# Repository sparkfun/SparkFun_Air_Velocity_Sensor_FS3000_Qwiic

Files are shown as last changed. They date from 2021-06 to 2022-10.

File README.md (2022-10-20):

SparkFun Air Velocity Sensor Breakout - FS3000 (Qwiic)
========================================

<table class="table table-hover table-striped table-bordered">
  <tr align="center">
   <td><a href="https://www.sparkfun.com/products/18377">SparkFun Air Velocity Sensor Breakout - FS3000-1005 (Qwiic)</a></td>
   <td><a href="https://www.sparkfun.com/products/18768">SparkFun Air Velocity Sensor Breakout - FS3000-1015 (Qwiic)</a></td>
  </tr>
  <tr align="center">
   <td><i>SparkFun Air Velocity Sensor Breakout <br /> FS3000-1005 (Qwiic) <br /> [ <a href="https://www.sparkfun.com/products/18377">SEN-18377</a> ]</i></td>
   <td><i>SparkFun Air Velocity Sensor Breakout <br /> FS3000-1015 (Qwiic) <br /> [ <a href="https://www.sparkfun.com/products/18768">SEN-18768</a> ]</i></td>
  </tr>
</table>

The SparkFun Air Velocity Sensor Breakout - FS3000 (Qwiic) makes it easy to use the Renesas FS3000 module. The FS3000 is a surface-mount type air velocity module utilizing a MEMS thermopile-based sensor. The FS3000 features a digital output with 12-bit resolution. The sensor comprises a "solid" thermal isolation technology and siliconcarbide coating to protect it from abrasive wear and water condensation. The FS3000 features a compact design fit for low profile enclosures.

There are two versions of this sensor with different upper ranges (1005/1015). This SparkFun product breaks out both versions on separate breakout boards: the 1005 version which can sense 0-7.23m/s (0-16.17mph) and 1015 version which can sense 0-15m/s (0-33.6mph).

SparkFun labored with love to create this code. Feel like supporting open source hardware?
Buy a [board](https://www.sparkfun.com/products/18377) or [two](https://www.sparkfun.com/products/18768) from SparkFun!

Repository Contents
-------------------

* **/Hardware** - Eagle design files (.brd, .sch)
* **/Hardware/Production** - Production panel files (.brd)
* **/Documents** - Datasheet, dimensional drawings.

Documentation
--------------

* **[Installing an Arduino Library Guide](https://learn.sparkfun.com/tutorials/installing-an-arduino-library)** - Basic information on how to install an Arduino library.
* **[Arduino Library](https://github.com/sparkfun/SparkFun_FS3000_Arduino_Library)** - Arduino Library for the Air Velocity Sensor FS3000.
* **[Hookup Guide](https://learn.sparkfun.com/tutorials/air-velocity-sensor-breakout---fs3000-hookup-guide)** - Hookup guide for the SparkFun Qwiic Air Velocity Sensor - FS3000.

Product Versions
----------------
* [SEN-18768](https://www.sparkfun.com/products/18768) - v1.0 with FS3000-1015
* [SEN-18377](https://www.sparkfun.com/products/18377) - v1.0 with FS3000-1005, Initial Release

License Information
-------------------

This product is _**open source**_! 

Please review the LICENSE.md file for license information. 

If you have any questions or concerns on licensing, please contact technical support on our [SparkFun forums](https://forum.sparkfun.com/viewforum.php?f=152).

Distributed as-is; no warranty is given.

- Your friends at SparkFun.

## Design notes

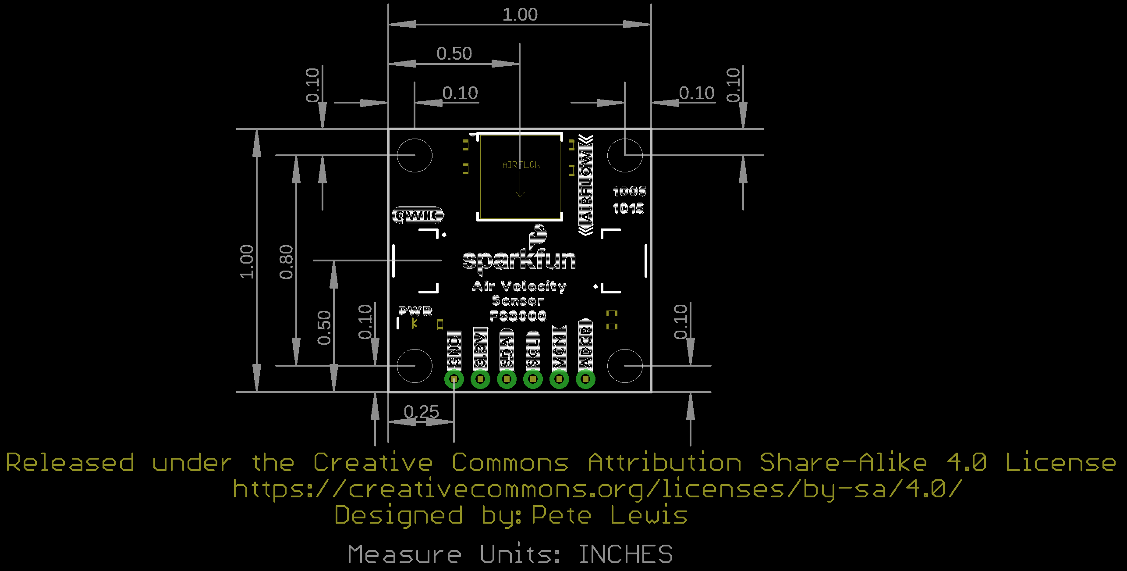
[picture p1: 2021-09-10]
Documents/FS3000_Qwiic_DIMENTIONS.png

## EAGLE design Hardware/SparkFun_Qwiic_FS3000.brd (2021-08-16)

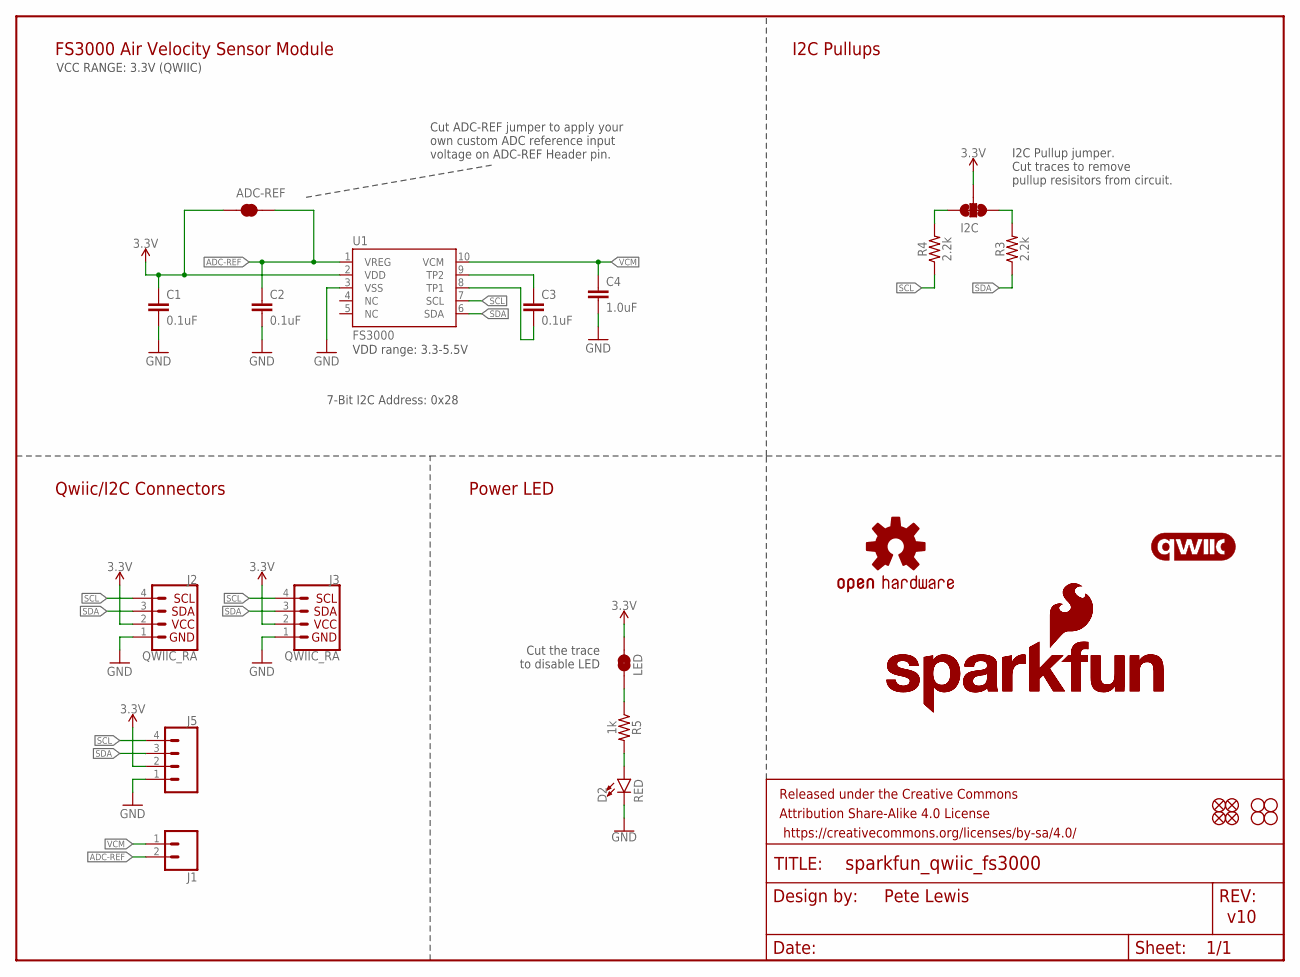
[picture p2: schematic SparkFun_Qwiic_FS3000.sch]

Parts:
ADC-REF: JUMPER-SMT_2_NC_TRACE_SILK; SMT-JUMPER_2_NC_TRACE_SILK
C1, C2, C3: 0.1uF; 0402-TIGHT
C4: 1.0uF; 0402-TIGHT
D2: RED; LED-0603
FRAME1: FRAME-LETTER; CREATIVE_COMMONS
I2C: JUMPER-SMT_3_2-NC_TRACE_SILK; SMT-JUMPER_3_2-NC_TRACE_SILK
J1: CONN_021X02_NO_SILK; 1X02_NO_SILK
J2, J3: QWIIC_RA; JST04_1MM_RA
J5: CONN_041X04_NO_SILK; 1X04_NO_SILK
JP1: LED; SMT-JUMPER_2_NC_TRACE_SILK
JP2, JP5, JP6, JP11: FIDUCIALUFIDUCIAL; FIDUCIAL-MICRO
JP3, JP4, JP7, JP8: STAND-OFF
LOGO1: OSHW-LOGOMINI; OSHW-LOGO-MINI
LOGO3, LOGO5: SFE_LOGO_NAME_FLAME.1_INCH; SFE_LOGO_NAME_FLAME_.1
LOGO4: QWIIC_LOGO_5MM; QWIIC_5MM
R3, R4: 2.2k; 0402-TIGHT
R5: 1k; 0402-TIGHT
U1: FS3000

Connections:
3.3V: ADC-REF.1, C1.1, I2C.2, J2.2, J3.2, J5.2, JP1.2, U1.2 (VDD)
ADC-REF: ADC-REF.2, C2.1, J1.2, U1.1 (VREG)
GND: C1.2, C2.2, C4.2, D2.C, J2.1, J3.1, J5.1, U1.3 (VSS)
unnamed: I2C.1, R3.2
unnamed: I2C.3, R4.2
unnamed: C3.1, U1.9 (TP2)
unnamed: C3.2, U1.8 (TP1)
unnamed: D2.A, R5.2
unnamed: JP1.1, R5.1
SCL: J2.4, J3.4, J5.4, R4.1, U1.7 (SCL)
SDA: J2.3, J3.3, J5.3, R3.1, U1.6 (SDA)
VCM: C4.1, J1.1, U1.10 (VCM)

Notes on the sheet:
7-Bit I2C Address: 0x28
Pete Lewis
v10
FS3000 Air Velocity Sensor Module
Qwiic/I2C Connectors
I2C Pullup jumper. Cut traces to remove pullup resisitors from circuit.
Cut the trace to disable LED
Power LED
VCC RANGE: 3.3V (QWIIC)
I2C Pullups
Cut ADC-REF jumper to apply your own custom ADC reference input voltage on ADC-REF Header pin.
VDD range: 3.3-5.5V

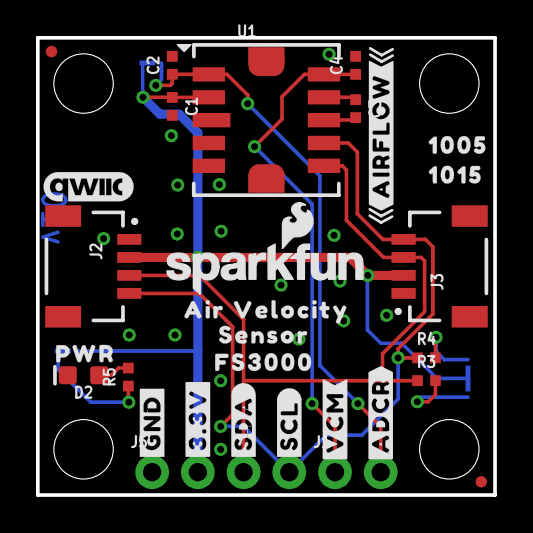
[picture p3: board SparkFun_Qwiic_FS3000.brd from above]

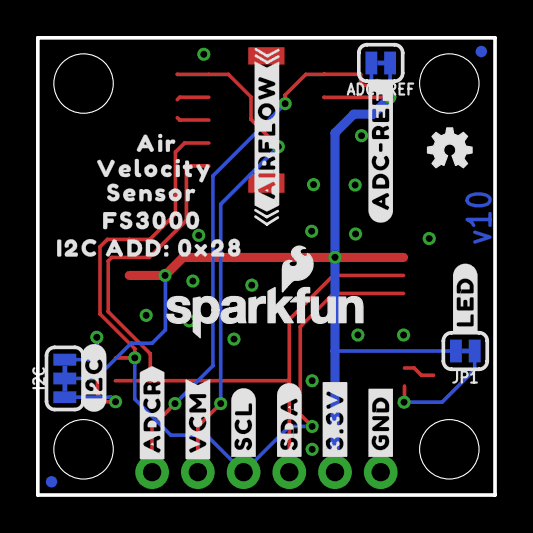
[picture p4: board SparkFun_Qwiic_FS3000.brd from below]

Board: 2 copper layers, 25.4 x 25.4 mm, 58 parts (22 on the bottom side), 12 nets.

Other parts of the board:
U$3, U$11: #SCL#0
U$4, U$9: #SDA#0
U$5, U$6: #GND#0
U$7, U$8: #3#3V#0
U$10, U$13: #ADCR#4
U$12: 10050
U$14, U$17: FS30001
U$15: #ADC#REF#0
U$16, U$20: VELOCITY30003
U$18, U$21: AIR30004
U$19, U$22: SENSOR30005
U$23, U$26: #AIRFLOW#0
U$24: #LED#0
U$25: PWR0
U$27: #I2C#0
U$28: I2C_ADD#_0X280
U$29: 10150
U$30, U$31: #VCM#3

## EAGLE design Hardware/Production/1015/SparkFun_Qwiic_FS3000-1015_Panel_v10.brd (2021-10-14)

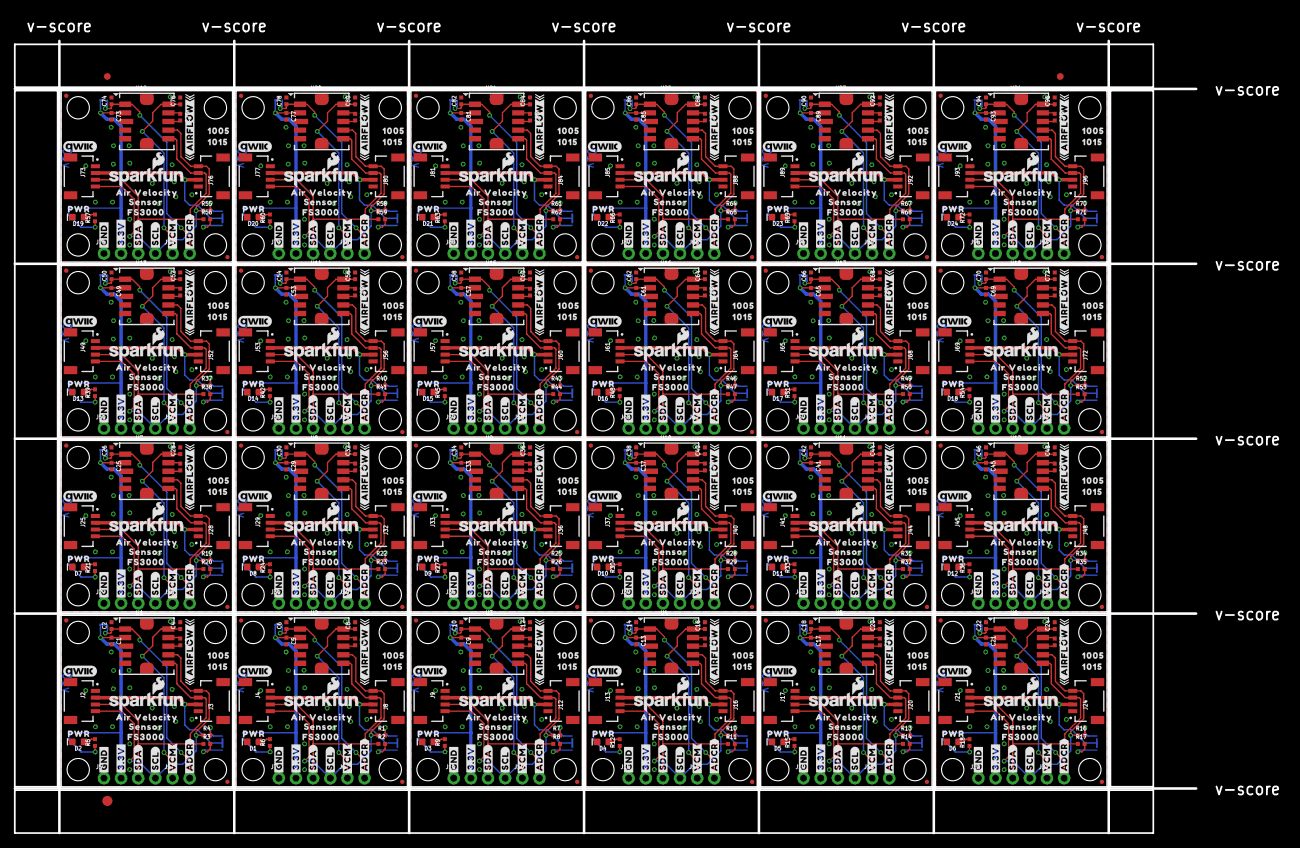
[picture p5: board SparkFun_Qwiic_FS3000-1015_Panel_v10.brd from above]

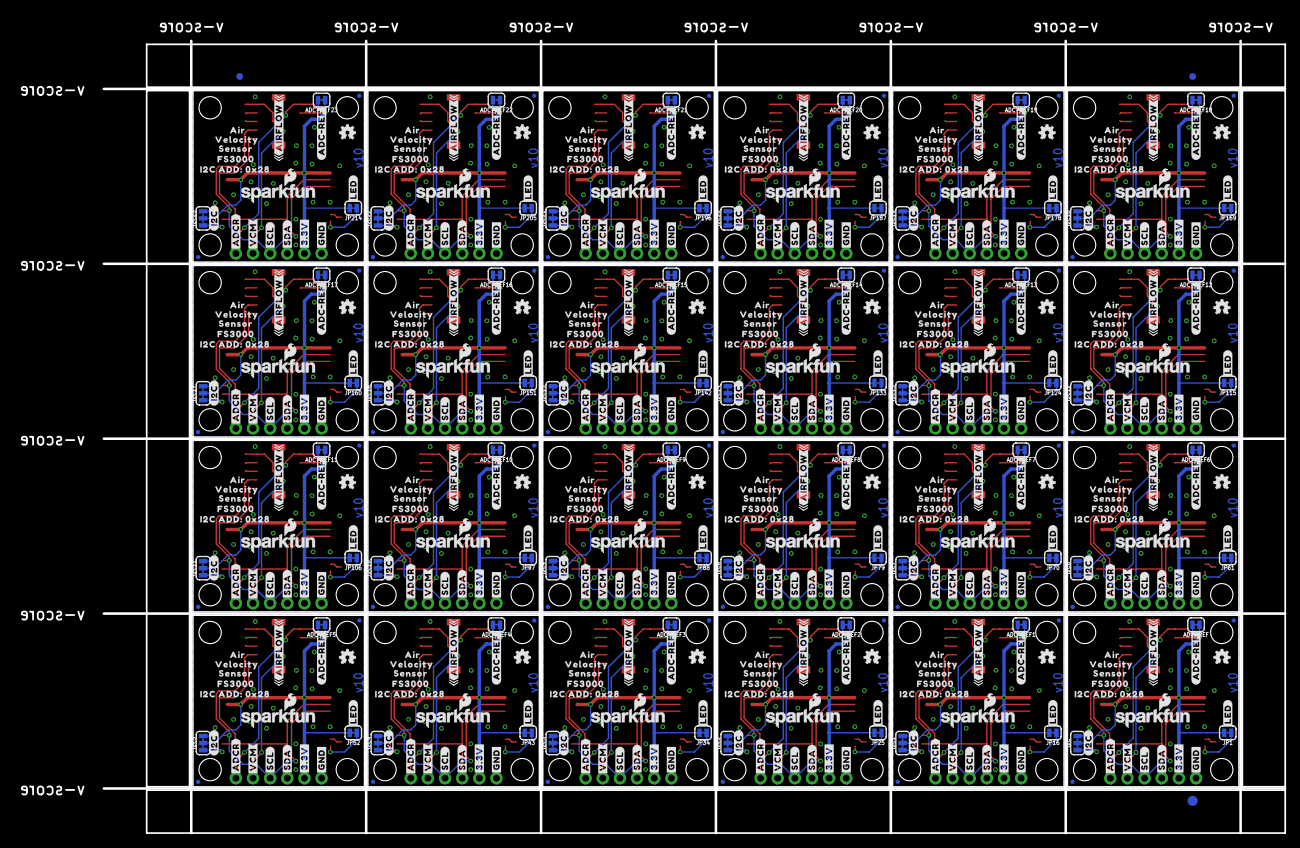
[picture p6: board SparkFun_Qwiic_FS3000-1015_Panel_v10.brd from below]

Board: 2 copper layers, 175.0 x 117.3 mm, 1374 parts (531 on the bottom side), 288 nets.

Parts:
ADC-REF, ADC-REF1, ADC-REF2, ADC-REF3, ADC-REF4, ADC-REF5, ADC-REF6, ADC-REF7, ADC-REF8, ADC-REF9, ADC-REF10, ADC-REF11, ADC-REF12, ADC-REF13, ADC-REF14, ADC-REF15, ADC-REF16, ADC-REF17, ADC-REF18, ADC-REF19, ADC-REF20, ADC-REF21, ADC-REF22, ADC-REF23: SMT-JUMPER_2_NC_TRACE_SILK
C1, C2, C3, C5, C6, C7, C9, C10, C11, C13, C14, C15, C17, C18, C19, C21, C22, C23, C25, C26, C27, C29, C30, C31, C33, C34, C35, C37, C38, C39, C41, C42, C43, C45, C46, C47, C49, C50, C51, C53, C54, C55, C57, C58, C59, C61, C62, C63, C65, C66, C67, C69, C70, C71, C73, C74, C75, C77, C78, C79, C81, C82, C83, C85, C86, C87, C89, C90, C91, C93, C94, C95: 0.1uF; 0402-TIGHT
C4, C8, C12, C16, C20, C24, C28, C32, C36, C40, C44, C48, C52, C56, C60, C64, C68, C72, C76, C80, C84, C88, C92, C96: 1.0uF; 0402-TIGHT
D1, D2, D3, D4, D5, D6, D7, D8, D9, D10, D11, D12, D13, D14, D15, D16, D17, D18, D19, D20, D21, D22, D23, D24: RED; LED-0603
E$1, E$2, E$3, E$4: FIDUCIAL-1X2
E$5, E$6: FIDUCIAL-1.5X3
I2C, I2C1, I2C2, I2C3, I2C4, I2C5, I2C6, I2C7, I2C8, I2C9, I2C10, I2C11, I2C12, I2C13, I2C14, I2C15, I2C16, I2C17, I2C18, I2C19, I2C20, I2C21, I2C22, I2C23: SMT-JUMPER_3_2-NC_TRACE_SILK
J1, J6, J10, J14, J18, J22, J26, J30, J34, J38, J42, J46, J50, J54, J58, J62, J66, J70, J74, J78, J82, J86, J90, J94: 1X02_NO_SILK
J2, J3, J4, J8, J9, J12, J13, J16, J17, J20, J21, J24, J25, J28, J29, J32, J33, J36, J37, J40, J41, J44, J45, J48, J49, J52, J53, J56, J57, J60, J61, J64, J65, J68, J69, J72, J73, J76, J77, J80, J81, J84, J85, J88, J89, J92, J93, J96: QWIIC_RA; JST04_1MM_RA
J5, J7, J11, J15, J19, J23, J27, J31, J35, J39, J43, J47, J51, J55, J59, J63, J67, J71, J75, J79, J83, J87, J91, J95: 1X04_NO_SILK
JP1, JP16, JP25, JP34, JP43, JP52, JP61, JP70, JP79, JP88, JP97, JP106, JP115, JP124, JP133, JP142, JP151, JP160, JP169, JP178, JP187, JP196, JP205, JP214: LED; SMT-JUMPER_2_NC_TRACE_SILK
JP2, JP5, JP6, JP10, JP11, JP12, JP13, JP14, JP20, JP21, JP22, JP23, JP29, JP30, JP31, JP32, JP38, JP39, JP40, JP41, JP47, JP48, JP49, JP50, JP56, JP57, JP58, JP59, JP65, JP66, JP67, JP68, JP74, JP75, JP76, JP77, JP83, JP84, JP85, JP86, JP92, JP93, JP94, JP95, JP101, JP102, JP103, JP104, JP110, JP111, JP112, JP113, JP119, JP120, JP121, JP122, JP128, JP129, JP130, JP131, JP137, JP138, JP139, JP140, JP146, JP147, JP148, JP149, JP155, JP156, JP157, JP158, JP164, JP165, JP166, JP167, JP173, JP174, JP175, JP176, JP182, JP183, JP184, JP185, JP191, JP192, JP193, JP194, JP200, JP201, JP202, JP203, JP209, JP210, JP211, JP212: FIDUCIALUFIDUCIAL; FIDUCIAL-MICRO
JP3, JP4, JP7, JP8, JP9, JP15, JP17, JP18, JP19, JP24, JP26, JP27, JP28, JP33, JP35, JP36, JP37, JP42, JP44, JP45, JP46, JP51, JP53, JP54, JP55, JP60, JP62, JP63, JP64, JP69, JP71, JP72, JP73, JP78, JP80, JP81, JP82, JP87, JP89, JP90, JP91, JP96, JP98, JP99, JP100, JP105, JP107, JP108, JP109, JP114, JP116, JP117, JP118, JP123, JP125, JP126, JP127, JP132, JP134, JP135, JP136, JP141, JP143, JP144, JP145, JP150, JP152, JP153, JP154, JP159, JP161, JP162, JP163, JP168, JP170, JP171, JP172, JP177, JP179, JP180, JP181, JP186, JP188, JP189, JP190, JP195, JP197, JP198, JP199, JP204, JP206, JP207, JP208, JP213, JP215, JP216: STAND-OFF
LOGO1, LOGO2, LOGO9, LOGO13, LOGO17, LOGO21, LOGO25, LOGO29, LOGO33, LOGO37, LOGO41, LOGO45, LOGO49, LOGO53, LOGO57, LOGO61, LOGO65, LOGO69, LOGO73, LOGO77, LOGO81, LOGO85, LOGO89, LOGO93: OSHW-LOGOMINI; OSHW-LOGO-MINI
LOGO3, LOGO5, LOGO7, LOGO8, LOGO11, LOGO12, LOGO15, LOGO16, LOGO19, LOGO20, LOGO23, LOGO24, LOGO27, LOGO28, LOGO31, LOGO32, LOGO35, LOGO36, LOGO39, LOGO40, LOGO43, LOGO44, LOGO47, LOGO48, LOGO51, LOGO52, LOGO55, LOGO56, LOGO59, LOGO60, LOGO63, LOGO64, LOGO67, LOGO68, LOGO71, LOGO72, LOGO75, LOGO76, LOGO79, LOGO80, LOGO83, LOGO84, LOGO87, LOGO88, LOGO91, LOGO92, LOGO95, LOGO96: SFE_LOGO_NAME_FLAME.1_INCH; SFE_LOGO_NAME_FLAME_.1
LOGO4, LOGO6, LOGO10, LOGO14, LOGO18, LOGO22, LOGO26, LOGO30, LOGO34, LOGO38, LOGO42, LOGO46, LOGO50, LOGO54, LOGO58, LOGO62, LOGO66, LOGO70, LOGO74, LOGO78, LOGO82, LOGO86, LOGO90, LOGO94: QWIIC_LOGO_5MM; QWIIC_5MM
R1, R2, R3, R4, R7, R8, R10, R11, R13, R14, R16, R17, R19, R20, R22, R23, R25, R26, R28, R29, R31, R32, R34, R35, R37, R38, R40, R41, R43, R44, R46, R47, R49, R50, R52, R53, R55, R56, R58, R59, R61, R62, R64, R65, R67, R68, R70, R71: 2.2k; 0402-TIGHT
R5, R6, R9, R12, R15, R18, R21, R24, R27, R30, R33, R36, R39, R42, R45, R48, R51, R54, R57, R60, R63, R66, R69, R72: 1k; 0402-TIGHT
U1, U2, U3, U4, U5, U6, U7, U8, U9, U10, U11, U12, U13, U14, U15, U16, U17, U18, U19, U20, U21, U22, U23, U24: FS3000
U$1, U$2, U$5, U$6, U$59, U$60, U$88, U$89, U$117, U$118, U$146, U$147, U$175, U$176, U$204, U$205, U$233, U$234, U$262, U$263, U$291, U$292, U$320, U$321, U$349, U$350, U$378, U$379, U$407, U$408, U$436, U$437, U$465, U$466, U$494, U$495, U$523, U$524, U$552, U$553, U$581, U$582, U$610, U$611, U$639, U$640, U$668, U$669: #GND#0
U$3, U$11, U$35, U$39, U$64, U$68, U$93, U$97, U$122, U$126, U$151, U$155, U$180, U$184, U$209, U$213, U$238, U$242, U$267, U$271, U$296, U$300, U$325, U$329, U$354, U$358, U$383, U$387, U$412, U$416, U$441, U$445, U$470, U$474, U$499, U$503, U$528, U$532, U$557, U$561, U$586, U$590, U$615, U$619, U$644, U$648, U$673, U$677: #SCL#0
U$4, U$9, U$34, U$40, U$63, U$69, U$92, U$98, U$121, U$127, U$150, U$156, U$179, U$185, U$208, U$214, U$237, U$243, U$266, U$272, U$295, U$301, U$324, U$330, U$353, U$359, U$382, U$388, U$411, U$417, U$440, U$446, U$469, U$475, U$498, U$504, U$527, U$533, U$556, U$562, U$585, U$591, U$614, U$620, U$643, U$649, U$672, U$678: #SDA#0
U$7, U$8, U$32, U$33, U$61, U$62, U$90, U$91, U$119, U$120, U$148, U$149, U$177, U$178, U$206, U$207, U$235, U$236, U$264, U$265, U$293, U$294, U$322, U$323, U$351, U$352, U$380, U$381, U$409, U$410, U$438, U$439, U$467, U$468, U$496, U$497, U$525, U$526, U$554, U$555, U$583, U$584, U$612, U$613, U$641, U$642, U$670, U$671: #3#3V#0
U$10, U$13, U$55, U$56, U$84, U$85, U$113, U$114, U$142, U$143, U$171, U$172, U$200, U$201, U$229, U$230, U$258, U$259, U$287, U$288, U$316, U$317, U$345, U$346, U$374, U$375, U$403, U$404, U$432, U$433, U$461, U$462, U$490, U$491, U$519, U$520, U$548, U$549, U$577, U$578, U$606, U$607, U$635, U$636, U$664, U$665, U$693, U$694: #ADCR#4
U$12, U$53, U$82, U$111, U$140, U$169, U$198, U$227, U$256, U$285, U$314, U$343, U$372, U$401, U$430, U$459, U$488, U$517, U$546, U$575, U$604, U$633, U$662, U$691: 10050
U$14, U$17, U$41, U$46, U$70, U$75, U$99, U$104, U$128, U$133, U$157, U$162, U$186, U$191, U$215, U$220, U$244, U$249, U$273, U$278, U$302, U$307, U$331, U$336, U$360, U$365, U$389, U$394, U$418, U$423, U$447, U$452, U$476, U$481, U$505, U$510, U$534, U$539, U$563, U$568, U$592, U$597, U$621, U$626, U$650, U$655, U$679, U$684: FS30001
U$15, U$45, U$74, U$103, U$132, U$161, U$190, U$219, U$248, U$277, U$306, U$335, U$364, U$393, U$422, U$451, U$480, U$509, U$538, U$567, U$596, U$625, U$654, U$683: #ADC#REF#0
U$16, U$20, U$42, U$47, U$71, U$76, U$100, U$105, U$129, U$134, U$158, U$163, U$187, U$192, U$216, U$221, U$245, U$250, U$274, U$279, U$303, U$308, U$332, U$337, U$361, U$366, U$390, U$395, U$419, U$424, U$448, U$453, U$477, U$482, U$506, U$511, U$535, U$540, U$564, U$569, U$593, U$598, U$622, U$627, U$651, U$656, U$680, U$685: VELOCITY30003
U$18, U$21, U$43, U$48, U$72, U$77, U$101, U$106, U$130, U$135, U$159, U$164, U$188, U$193, U$217, U$222, U$246, U$251, U$275, U$280, U$304, U$309, U$333, U$338, U$362, U$367, U$391, U$396, U$420, U$425, U$449, U$454, U$478, U$483, U$507, U$512, U$536, U$541, U$565, U$570, U$594, U$599, U$623, U$628, U$652, U$657, U$681, U$686: AIR30004
U$19, U$22, U$44, U$49, U$73, U$78, U$102, U$107, U$131, U$136, U$160, U$165, U$189, U$194, U$218, U$223, U$247, U$252, U$276, U$281, U$305, U$310, U$334, U$339, U$363, U$368, U$392, U$397, U$421, U$426, U$450, U$455, U$479, U$484, U$508, U$513, U$537, U$542, U$566, U$571, U$595, U$600, U$624, U$629, U$653, U$658, U$682, U$687: SENSOR30005
U$23, U$26, U$50, U$51, U$79, U$80, U$108, U$109, U$137, U$138, U$166, U$167, U$195, U$196, U$224, U$225, U$253, U$254, U$282, U$283, U$311, U$312, U$340, U$341, U$369, U$370, U$398, U$399, U$427, U$428, U$456, U$457, U$485, U$486, U$514, U$515, U$543, U$544, U$572, U$573, U$601, U$602, U$630, U$631, U$659, U$660, U$688, U$689: #AIRFLOW#0
U$24, U$36, U$65, U$94, U$123, U$152, U$181, U$210, U$239, U$268, U$297, U$326, U$355, U$384, U$413, U$442, U$471, U$500, U$529, U$558, U$587, U$616, U$645, U$674: #LED#0
U$25, U$37, U$66, U$95, U$124, U$153, U$182, U$211, U$240, U$269, U$298, U$327, U$356, U$385, U$414, U$443, U$472, U$501, U$530, U$559, U$588, U$617, U$646, U$675: PWR0
U$27, U$38, U$67, U$96, U$125, U$154, U$183, U$212, U$241, U$270, U$299, U$328, U$357, U$386, U$415, U$444, U$473, U$502, U$531, U$560, U$589, U$618, U$647, U$676: #I2C#0
U$28, U$52, U$81, U$110, U$139, U$168, U$197, U$226, U$255, U$284, U$313, U$342, U$371, U$400, U$429, U$458, U$487, U$516, U$545, U$574, U$603, U$632, U$661, U$690: I2C_ADD#_0X280
U$29, U$54, U$83, U$112, U$141, U$170, U$199, U$228, U$257, U$286, U$315, U$344, U$373, U$402, U$431, U$460, U$489, U$518, U$547, U$576, U$605, U$634, U$663, U$692: 10150
U$30, U$31, U$57, U$58, U$86, U$87, U$115, U$116, U$144, U$145, U$173, U$174, U$202, U$203, U$231, U$232, U$260, U$261, U$289, U$290, U$318, U$319, U$347, U$348, U$376, U$377, U$405, U$406, U$434, U$435, U$463, U$464, U$492, U$493, U$521, U$522, U$550, U$551, U$579, U$580, U$608, U$609, U$637, U$638, U$666, U$667, U$695, U$696: #VCM#3

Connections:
3.3V: ADC-REF.1, C1.1, I2C.2, J2.2, J3.2, J5.2, JP1.2, U1.2
3.3V1: ADC-REF1.1, C5.1, I2C1.2, J4.2, J7.2, J8.2, JP16.2, U2.2
3.3V2: ADC-REF2.1, C9.1, I2C2.2, J9.2, J11.2, J12.2, JP25.2, U3.2
3.3V3: ADC-REF3.1, C13.1, I2C3.2, J13.2, J15.2, J16.2, JP34.2, U4.2
3.3V4: ADC-REF4.1, C17.1, I2C4.2, J17.2, J19.2, J20.2, JP43.2, U5.2
3.3V5: ADC-REF5.1, C21.1, I2C5.2, J21.2, J23.2, J24.2, JP52.2, U6.2
3.3V6: ADC-REF6.1, C25.1, I2C6.2, J25.2, J27.2, J28.2, JP61.2, U7.2
3.3V7: ADC-REF7.1, C29.1, I2C7.2, J29.2, J31.2, J32.2, JP70.2, U8.2
3.3V8: ADC-REF8.1, C33.1, I2C8.2, J33.2, J35.2, J36.2, JP79.2, U9.2
3.3V9: ADC-REF9.1, C37.1, I2C9.2, J37.2, J39.2, J40.2, JP88.2, U10.2
3.3V10: ADC-REF10.1, C41.1, I2C10.2, J41.2, J43.2, J44.2, JP97.2, U11.2
3.3V11: ADC-REF11.1, C45.1, I2C11.2, J45.2, J47.2, J48.2, JP106.2, U12.2
3.3V12: ADC-REF12.1, C49.1, I2C12.2, J49.2, J51.2, J52.2, JP115.2, U13.2
3.3V13: ADC-REF13.1, C53.1, I2C13.2, J53.2, J55.2, J56.2, JP124.2, U14.2
3.3V14: ADC-REF14.1, C57.1, I2C14.2, J57.2, J59.2, J60.2, JP133.2, U15.2
3.3V15: ADC-REF15.1, C61.1, I2C15.2, J61.2, J63.2, J64.2, JP142.2, U16.2
3.3V16: ADC-REF16.1, C65.1, I2C16.2, J65.2, J67.2, J68.2, JP151.2, U17.2
3.3V17: ADC-REF17.1, C69.1, I2C17.2, J69.2, J71.2, J72.2, JP160.2, U18.2
3.3V18: ADC-REF18.1, C73.1, I2C18.2, J73.2, J75.2, J76.2, JP169.2, U19.2
3.3V19: ADC-REF19.1, C77.1, I2C19.2, J77.2, J79.2, J80.2, JP178.2, U20.2
3.3V20: ADC-REF20.1, C81.1, I2C20.2, J81.2, J83.2, J84.2, JP187.2, U21.2
3.3V21: ADC-REF21.1, C85.1, I2C21.2, J85.2, J87.2, J88.2, JP196.2, U22.2
3.3V22: ADC-REF22.1, C89.1, I2C22.2, J89.2, J91.2, J92.2, JP205.2, U23.2
3.3V23: ADC-REF23.1, C93.1, I2C23.2, J93.2, J95.2, J96.2, JP214.2, U24.2
ADC-REF: ADC-REF.2, C2.1, J1.2, U1.1
ADC-REF1: ADC-REF1.2, C6.1, J6.2, U2.1
ADC-REF2: ADC-REF2.2, C10.1, J10.2, U3.1
ADC-REF3: ADC-REF3.2, C14.1, J14.2, U4.1
ADC-REF4: ADC-REF4.2, C18.1, J18.2, U5.1
ADC-REF5: ADC-REF5.2, C22.1, J22.2, U6.1
ADC-REF6: ADC-REF6.2, C26.1, J26.2, U7.1
ADC-REF7: ADC-REF7.2, C30.1, J30.2, U8.1
ADC-REF8: ADC-REF8.2, C34.1, J34.2, U9.1
ADC-REF9: ADC-REF9.2, C38.1, J38.2, U10.1
ADC-REF10: ADC-REF10.2, C42.1, J42.2, U11.1
ADC-REF11: ADC-REF11.2, C46.1, J46.2, U12.1
ADC-REF12: ADC-REF12.2, C50.1, J50.2, U13.1
ADC-REF13: ADC-REF13.2, C54.1, J54.2, U14.1
ADC-REF14: ADC-REF14.2, C58.1, J58.2, U15.1
ADC-REF15: ADC-REF15.2, C62.1, J62.2, U16.1
ADC-REF16: ADC-REF16.2, C66.1, J66.2, U17.1
ADC-REF17: ADC-REF17.2, C70.1, J70.2, U18.1
ADC-REF18: ADC-REF18.2, C74.1, J74.2, U19.1
ADC-REF19: ADC-REF19.2, C78.1, J78.2, U20.1
ADC-REF20: ADC-REF20.2, C82.1, J82.2, U21.1
ADC-REF21: ADC-REF21.2, C86.1, J86.2, U22.1
ADC-REF22: ADC-REF22.2, C90.1, J90.2, U23.1
ADC-REF23: ADC-REF23.2, C94.1, J94.2, U24.1
GND: C1.2, C2.2, C4.2, D2.C, J2.1, J3.1, J5.1, U1.3
GND1: C5.2, C6.2, C8.2, D1.C, J4.1, J7.1, J8.1, U2.3
GND2: C9.2, C10.2, C12.2, D3.C, J9.1, J11.1, J12.1, U3.3
GND3: C13.2, C14.2, C16.2, D4.C, J13.1, J15.1, J16.1, U4.3
GND4: C17.2, C18.2, C20.2, D5.C, J17.1, J19.1, J20.1, U5.3
GND5: C21.2, C22.2, C24.2, D6.C, J21.1, J23.1, J24.1, U6.3
GND6: C25.2, C26.2, C28.2, D7.C, J25.1, J27.1, J28.1, U7.3
GND7: C29.2, C30.2, C32.2, D8.C, J29.1, J31.1, J32.1, U8.3
GND8: C33.2, C34.2, C36.2, D9.C, J33.1, J35.1, J36.1, U9.3
GND9: C37.2, C38.2, C40.2, D10.C, J37.1, J39.1, J40.1, U10.3
GND10: C41.2, C42.2, C44.2, D11.C, J41.1, J43.1, J44.1, U11.3
GND11: C45.2, C46.2, C48.2, D12.C, J45.1, J47.1, J48.1, U12.3
GND12: C49.2, C50.2, C52.2, D13.C, J49.1, J51.1, J52.1, U13.3
GND13: C53.2, C54.2, C56.2, D14.C, J53.1, J55.1, J56.1, U14.3
GND14: C57.2, C58.2, C60.2, D15.C, J57.1, J59.1, J60.1, U15.3
GND15: C61.2, C62.2, C64.2, D16.C, J61.1, J63.1, J64.1, U16.3
GND16: C65.2, C66.2, C68.2, D17.C, J65.1, J67.1, J68.1, U17.3
GND17: C69.2, C70.2, C72.2, D18.C, J69.1, J71.1, J72.1, U18.3
GND18: C73.2, C74.2, C76.2, D19.C, J73.1, J75.1, J76.1, U19.3
GND19: C77.2, C78.2, C80.2, D20.C, J77.1, J79.1, J80.1, U20.3
GND20: C81.2, C82.2, C84.2, D21.C, J81.1, J83.1, J84.1, U21.3
GND21: C85.2, C86.2, C88.2, D22.C, J85.1, J87.1, J88.1, U22.3
GND22: C89.2, C90.2, C92.2, D23.C, J89.1, J91.1, J92.1, U23.3
GND23: C93.2, C94.2, C96.2, D24.C, J93.1, J95.1, J96.1, U24.3
unnamed: I2C.1, R3.2
unnamed: I2C.3, R4.2
unnamed: C3.1, U1.9
unnamed: C3.2, U1.8
unnamed: I2C1.1, R2.2
unnamed: D2.A, R5.2
unnamed: I2C1.3, R1.2
unnamed: JP1.1, R5.1
unnamed: D1.A, R6.2
unnamed: JP16.1, R6.1
unnamed: C7.1, U2.9
unnamed: C7.2, U2.8
unnamed: I2C2.1, R8.2
unnamed: I2C2.3, R7.2
unnamed: D3.A, R9.2
unnamed: JP25.1, R9.1
unnamed: C11.1, U3.9
unnamed: C11.2, U3.8
unnamed: I2C3.1, R11.2
unnamed: I2C3.3, R10.2
unnamed: D4.A, R12.2
unnamed: JP34.1, R12.1
unnamed: C15.1, U4.9
unnamed: C15.2, U4.8
unnamed: I2C4.1, R14.2
unnamed: I2C4.3, R13.2
unnamed: D5.A, R15.2
unnamed: JP43.1, R15.1
unnamed: C19.1, U5.9
unnamed: C19.2, U5.8
unnamed: I2C5.1, R17.2
unnamed: I2C5.3, R16.2
unnamed: D6.A, R18.2
unnamed: JP52.1, R18.1
unnamed: C23.1, U6.9
unnamed: C23.2, U6.8
unnamed: I2C6.1, R20.2
unnamed: I2C6.3, R19.2
unnamed: D7.A, R21.2
unnamed: JP61.1, R21.1
unnamed: C27.1, U7.9
unnamed: C27.2, U7.8
unnamed: I2C7.1, R23.2
unnamed: I2C7.3, R22.2
unnamed: D8.A, R24.2
unnamed: JP70.1, R24.1
unnamed: C31.1, U8.9
unnamed: C31.2, U8.8
unnamed: I2C8.1, R26.2
unnamed: I2C8.3, R25.2
unnamed: D9.A, R27.2
unnamed: JP79.1, R27.1
unnamed: C35.1, U9.9
unnamed: C35.2, U9.8
unnamed: I2C9.1, R29.2
unnamed: I2C9.3, R28.2
unnamed: D10.A, R30.2
unnamed: JP88.1, R30.1
unnamed: C39.1, U10.9
unnamed: C39.2, U10.8
unnamed: I2C10.1, R32.2
unnamed: I2C10.3, R31.2
unnamed: D11.A, R33.2
unnamed: JP97.1, R33.1
unnamed: C43.1, U11.9
unnamed: C43.2, U11.8
unnamed: I2C11.1, R35.2
unnamed: I2C11.3, R34.2
unnamed: D12.A, R36.2
unnamed: JP106.1, R36.1
unnamed: C47.1, U12.9
unnamed: C47.2, U12.8
unnamed: I2C12.1, R38.2
unnamed: I2C12.3, R37.2
unnamed: D13.A, R39.2
unnamed: JP115.1, R39.1
unnamed: C51.1, U13.9
unnamed: C51.2, U13.8
unnamed: I2C13.1, R41.2
unnamed: I2C13.3, R40.2
unnamed: D14.A, R42.2
unnamed: JP124.1, R42.1
unnamed: C55.1, U14.9
unnamed: C55.2, U14.8
unnamed: I2C14.1, R44.2
unnamed: I2C14.3, R43.2
unnamed: D15.A, R45.2
unnamed: JP133.1, R45.1
unnamed: C59.1, U15.9
unnamed: C59.2, U15.8
unnamed: I2C15.1, R47.2
unnamed: I2C15.3, R46.2
unnamed: D16.A, R48.2
unnamed: JP142.1, R48.1
unnamed: C63.1, U16.9
unnamed: C63.2, U16.8
unnamed: I2C16.1, R50.2
unnamed: I2C16.3, R49.2
unnamed: D17.A, R51.2
unnamed: JP151.1, R51.1
unnamed: C67.1, U17.9
unnamed: C67.2, U17.8
unnamed: I2C17.1, R53.2
unnamed: I2C17.3, R52.2
unnamed: D18.A, R54.2
unnamed: JP160.1, R54.1
unnamed: C71.1, U18.9
unnamed: C71.2, U18.8
unnamed: I2C18.1, R56.2
unnamed: I2C18.3, R55.2
unnamed: D19.A, R57.2
unnamed: JP169.1, R57.1
unnamed: C75.1, U19.9
unnamed: C75.2, U19.8
unnamed: I2C19.1, R59.2
unnamed: I2C19.3, R58.2
unnamed: D20.A, R60.2
unnamed: JP178.1, R60.1
unnamed: C79.1, U20.9
unnamed: C79.2, U20.8
unnamed: I2C20.1, R62.2
unnamed: I2C20.3, R61.2
unnamed: D21.A, R63.2
unnamed: JP187.1, R63.1
unnamed: C83.1, U21.9
unnamed: C83.2, U21.8
unnamed: I2C21.1, R65.2
unnamed: I2C21.3, R64.2
unnamed: D22.A, R66.2
unnamed: JP196.1, R66.1
unnamed: C87.1, U22.9
unnamed: C87.2, U22.8
unnamed: I2C22.1, R68.2
unnamed: I2C22.3, R67.2
unnamed: D23.A, R69.2
unnamed: JP205.1, R69.1
unnamed: C91.1, U23.9
unnamed: C91.2, U23.8
unnamed: I2C23.1, R71.2
unnamed: I2C23.3, R70.2
unnamed: D24.A, R72.2
unnamed: JP214.1, R72.1
unnamed: C95.1, U24.9
unnamed: C95.2, U24.8
SCL: J2.4, J3.4, J5.4, R4.1, U1.7
SCL1: J4.4, J7.4, J8.4, R1.1, U2.7
SCL2: J9.4, J11.4, J12.4, R7.1, U3.7
SCL3: J13.4, J15.4, J16.4, R10.1, U4.7
SCL4: J17.4, J19.4, J20.4, R13.1, U5.7
SCL5: J21.4, J23.4, J24.4, R16.1, U6.7
SCL6: J25.4, J27.4, J28.4, R19.1, U7.7
SCL7: J29.4, J31.4, J32.4, R22.1, U8.7
SCL8: J33.4, J35.4, J36.4, R25.1, U9.7
SCL9: J37.4, J39.4, J40.4, R28.1, U10.7
SCL10: J41.4, J43.4, J44.4, R31.1, U11.7
SCL11: J45.4, J47.4, J48.4, R34.1, U12.7
SCL12: J49.4, J51.4, J52.4, R37.1, U13.7
SCL13: J53.4, J55.4, J56.4, R40.1, U14.7
SCL14: J57.4, J59.4, J60.4, R43.1, U15.7
SCL15: J61.4, J63.4, J64.4, R46.1, U16.7
SCL16: J65.4, J67.4, J68.4, R49.1, U17.7
SCL17: J69.4, J71.4, J72.4, R52.1, U18.7
SCL18: J73.4, J75.4, J76.4, R55.1, U19.7
SCL19: J77.4, J79.4, J80.4, R58.1, U20.7
SCL20: J81.4, J83.4, J84.4, R61.1, U21.7
SCL21: J85.4, J87.4, J88.4, R64.1, U22.7
SCL22: J89.4, J91.4, J92.4, R67.1, U23.7
SCL23: J93.4, J95.4, J96.4, R70.1, U24.7
SDA: J2.3, J3.3, J5.3, R3.1, U1.6
SDA1: J4.3, J7.3, J8.3, R2.1, U2.6
SDA2: J9.3, J11.3, J12.3, R8.1, U3.6
SDA3: J13.3, J15.3, J16.3, R11.1, U4.6
SDA4: J17.3, J19.3, J20.3, R14.1, U5.6
SDA5: J21.3, J23.3, J24.3, R17.1, U6.6
SDA6: J25.3, J27.3, J28.3, R20.1, U7.6
SDA7: J29.3, J31.3, J32.3, R23.1, U8.6
SDA8: J33.3, J35.3, J36.3, R26.1, U9.6
SDA9: J37.3, J39.3, J40.3, R29.1, U10.6
SDA10: J41.3, J43.3, J44.3, R32.1, U11.6
SDA11: J45.3, J47.3, J48.3, R35.1, U12.6
SDA12: J49.3, J51.3, J52.3, R38.1, U13.6
SDA13: J53.3, J55.3, J56.3, R41.1, U14.6
SDA14: J57.3, J59.3, J60.3, R44.1, U15.6
SDA15: J61.3, J63.3, J64.3, R47.1, U16.6
SDA16: J65.3, J67.3, J68.3, R50.1, U17.6
SDA17: J69.3, J71.3, J72.3, R53.1, U18.6
SDA18: J73.3, J75.3, J76.3, R56.1, U19.6
SDA19: J77.3, J79.3, J80.3, R59.1, U20.6
SDA20: J81.3, J83.3, J84.3, R62.1, U21.6
SDA21: J85.3, J87.3, J88.3, R65.1, U22.6
SDA22: J89.3, J91.3, J92.3, R68.1, U23.6
SDA23: J93.3, J95.3, J96.3, R71.1, U24.6
VCM: C4.1, J1.1, U1.10
VCM1: C8.1, J6.1, U2.10
VCM2: C12.1, J10.1, U3.10
VCM3: C16.1, J14.1, U4.10
VCM4: C20.1, J18.1, U5.10
VCM5: C24.1, J22.1, U6.10
VCM6: C28.1, J26.1, U7.10
VCM7: C32.1, J30.1, U8.10
VCM8: C36.1, J34.1, U9.10
VCM9: C40.1, J38.1, U10.10
VCM10: C44.1, J42.1, U11.10
VCM11: C48.1, J46.1, U12.10
VCM12: C52.1, J50.1, U13.10
VCM13: C56.1, J54.1, U14.10
VCM14: C60.1, J58.1, U15.10
VCM15: C64.1, J62.1, U16.10
VCM16: C68.1, J66.1, U17.10
VCM17: C72.1, J70.1, U18.10
VCM18: C76.1, J74.1, U19.10
VCM19: C80.1, J78.1, U20.10
VCM20: C84.1, J82.1, U21.10
VCM21: C88.1, J86.1, U22.10
VCM22: C92.1, J90.1, U23.10
VCM23: C96.1, J94.1, U24.10

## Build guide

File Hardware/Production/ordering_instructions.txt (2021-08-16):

panel size, 169x117mm
PCB thickness, 1.6mm
number of layers, 2
soldermask color, Red
silkscreen color, White
oz copper, 1oz
finish, HASL lead free
stencils, top
pcs per panel, 24
min trace width, 0.2032mm / 0.0080in
min drill size, 0.3810mm / 0.0150in

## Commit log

2021-06-17 Initial layout started
    [SparkFun_Qwiic_FS3000.brd, SparkFun_Qwiic_FS3000.sch]
2021-06-17 Layout done
    [SparkFun_Qwiic_FS3000.brd, SparkFun_Qwiic_FS3000.sch]
2021-06-17 ran checklist pre-group review
    -DRC update
    -measures update
    -paste reduced on IC pads
    [SparkFun_Qwiic_FS3000.brd, SparkFun_Qwiic_FS3000.sch]
2021-06-18 created alternate option with sensor at "top" edge of PCB
    [SparkFun_Qwiic_FS3000_top.brd, SparkFun_Qwiic_FS3000_top.sch]
2021-06-18 manufacturing tab color changed to red, proto pic updated to show both options
    [SparkFun_Qwiic_FS3000.brd, SparkFun_Qwiic_FS3000_top.brd]
2021-06-18 Group Review Changes
    -Buzzard labels on VCM/ADCR changed to be correct inputs/outputs end type
    -Added in solder pads for two versions (7.23m/s vs 15m/s) (1005/1015)
    -Moved"supply range" to below the IC and change to "VDD range".
    -schematic cleanup - power LED jumper paragraph. space in I2C address.
    -added space between "I2C address" and "0x28" in board silk
    -added name/flame logo to board silk.
    [SparkFun_Qwiic_FS3000.brd, SparkFun_Qwiic_FS3000.sch, SparkFun_Qwiic_FS3000_top.brd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]
2021-06-18 Renaming and reorganizing to "TEE" and "1X1"
    Going to prototype with both designs to determine if TEE shape has better/different performance.
    [SparkFun_Qwiic_FS3000_1X1.brd, SparkFun_Qwiic_FS3000_1X1.sch, SparkFun_Qwiic_FS3000_TEE.brd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]
2021-06-21 eng ran checklist before double-check request
    -dimensions were off grid slightly, corrected [1X1 version].
    -approved DRC overlap error on jumper [1X1 version].
    -added a couple more stitching GND vias [1X1]
    -updated pad 3 to extend longer as shown in datasheet [both versions]
    [SparkFun_Qwiic_FS3000_1X1.brd, SparkFun_Qwiic_FS3000_1X1.sch, SparkFun_Qwiic_FS3000_TEE.brd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]
2021-06-21 updated some stuff to correct recent libraries
    -GNDs, Fiducials, and standoffs were still in old library. updated.
    [SparkFun_Qwiic_FS3000_1X1.brd, SparkFun_Qwiic_FS3000_1X1.sch, SparkFun_Qwiic_FS3000_TEE.brd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]
2021-06-22 Proto panel and gerbers
    -Made a proto panel that includes 3 copies of each design. This allows us to order a single stencil and saves production time when building 3 prototype copies of each (1X1 and TEE) by hand.
    -note, I had to move the VCM and ADCR buzzard labels on the 1x1 to a separate library, so I could drop it into the "proto panel" without it updating/breaking the other design.
    [SparkFun_Qwiic_FS3000_proto_panel.brd]
2021-06-23 re-panelized proto to meet 70cm width requirement for V-Scores
    [SparkFun_Qwiic_FS3000_proto_panel_b.brd]
2021-06-24 Removed leftover tStop/tCream for IC type on 1X1s
    [SparkFun_Qwiic_FS3000_proto_panel_c.brd]
2021-08-13 Decided to use 1X1 version, bumped version to "v10"
    [SparkFun_Qwiic_FS3000.brd, SparkFun_Qwiic_FS3000.sch, SparkFun_Qwiic_FS3000_1X1.brd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]
2021-08-16 version jumper switched to complete rectangle pad w/paste
    [SparkFun_Qwiic_FS3000.brd]
2021-08-16 production panel v10b
    [SparkFun_Qwiic_FS3000-Panel.brd]
2021-10-14 Gerbers for 1015 version that include GTP blob for 1015 pad/version
    Note, I just copied the panel file and shifted the tCream rectangles so they line up with the rectangle mask openings next to the 1015 silk text.
    [SparkFun_Qwiic_FS3000-1015_Panel_v10.GBL, SparkFun_Qwiic_FS3000-1015_Panel_v10.GBP, SparkFun_Qwiic_FS3000-1015_Panel_v10.GBS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]

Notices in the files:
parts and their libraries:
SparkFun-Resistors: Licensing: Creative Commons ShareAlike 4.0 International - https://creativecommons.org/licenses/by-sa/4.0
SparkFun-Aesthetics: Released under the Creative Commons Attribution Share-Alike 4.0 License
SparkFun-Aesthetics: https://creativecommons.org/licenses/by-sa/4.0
